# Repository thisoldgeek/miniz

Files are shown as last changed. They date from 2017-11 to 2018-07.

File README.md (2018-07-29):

# **miniz internet radio**
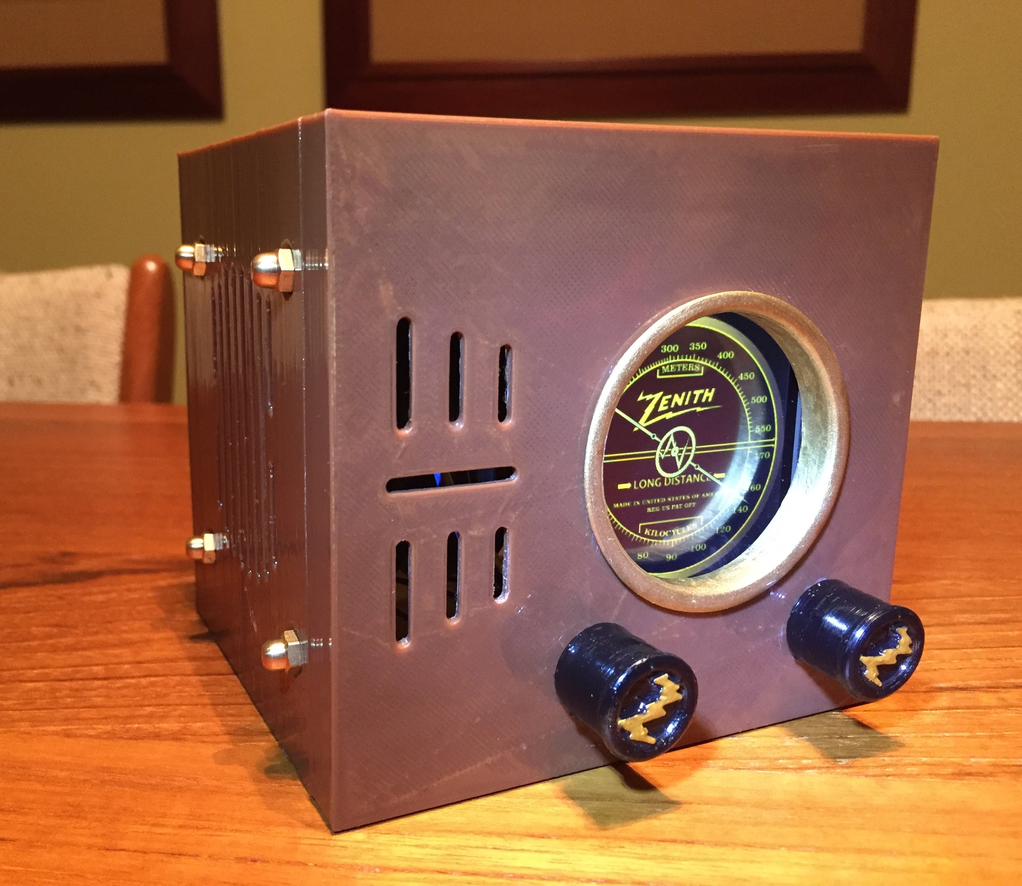
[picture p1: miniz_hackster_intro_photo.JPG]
miniz radio miniz Streaming Radio


# *Acknowledgements:*
My grateful appreciation is extended to the following, without whom this project would never exist, 
and to various Makers and members of the Open Source community for their continued sharing and support.

Tinkernut, https://www.hackster.io/tinkernut/diy-vintage-spotify-radio-using-a-raspberry-pi-bc3322

gerrelt, http://www.gerrelt.nl/RaspberryPi/wordpress/tutorial-stand-alone-squeezebox-server-and-player-for-bbq/

Oliver Derks, pi3d clock, https://groups.google.com/forum/#!topic/pi3d/qls3MQbtLiA

Bob Rathbone, rotary encoders, http://www.bobrathbone.com/raspberrypi/Raspberry%20Rotary%20Encoders.pdf

jinglemansweep on github, pyLMS, https://github.com/jinglemansweep/PyLMS

pi3d written by Tim Skillman, Paddy Gaunt, Tom Ritchford Copyright © 2012 - 2017, https://github.com/tipam/pi3d

Adafruit, various but especially, https://learn.adafruit.com/running-opengl-based-games-and-emulators-on-adafruit-pitft-displays/pitft-setup

trendblog: Mark Knoll, running headless pi, http://trendblog.net/raspberry-pi-basic-headless-setup-without-cables/

## *Description:*
A mono radio that plays favorite Pandora channels, internet radio stations, podcasts, playlists and 
local music using Logitech Media System and SqueezeLite. 

In the as-built version of this project, I'm using the free downloadable Deco typefont from Nick Curtis, called "Dubba Dubba". If you like Nick's work, please contribute a few $$ at: http://www.1001fonts.com/search.html?search=dubba+dubba&x=10&y=6

See the posting at (future):
http://thisoldgeek.blogspot.com

hackster.io miniz

## *Required Hardware:*
* raspberry pi zero W
* Adafruit piTFT Plus 3.5in display
* Small Speaker (3 inch full-range)
* Adafruit mono i2s amp, product 3006
* Adafruit perma-proto bonnet, product 3203
* Pimoroni On-Off/SHIM, Adafruit product 3581
* 2x rotary encoders with on/off switch, Adafruit product 377
* Optional but highly recommended: right-angle micro-usb to barrel connector
* Miscellaneous screws, nuts, standoffs, 22AWG wire

## *Fabrication:*
* 3D print files in STL_files folder
* 3D printed case required; other 3d parts optional
* See docs folder for 3D print settings

## *Configuration:*
* Install python programs and run scripts. See tutorial at hackster.io/thisoldgeek

Change IP Address to the IP of your miniz
Change player_id to your player from LMS/Settings/Information MAC Address

If you'd like to add additional "radio stations"

Consult the miniz/docs file name miniZ_dial_frequency_map.png and change the /miniz/miniz.py program

*format below is degrees:fav_number

favs = {82:0,57:1,30:2,8:3,352:4,333:5}

## *Testing:*
Use miniz/test_rotary_switches.py to test the tune and volume rotary encoder wiring and functions
Pin numbers in test_rotary_switches.py are the same as in miniz.py

## *REQUIRED:*
Intentionally blank

## *More Information:*
See the build log at https://www.hackster.io/thisoldgeek/miniz-tiny-streaming-radio-based-on-classic-zenith-cube-cbbc3e
## *Update 11-19-2017:*
Initial install.

## *UPDATE 2018-07-29: *
Added script miniz_dial_positions.py. Use this program to map a radio frequency on the dial to degrees of a circle
Degrees of a circle are used to play Favorites. 
*Usage*
Stop the zdial service.
Run the program, tune to a desired radio frequency on the dial. The degrees of circle for that frequency appears below
the center of the dial in white letters. Associate that degree with the favorite you wish to play at that frequency 
in the "favs:" dictionary of the miniz.py script

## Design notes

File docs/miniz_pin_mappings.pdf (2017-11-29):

MiniZ Streamer – Pin Mapping
All pin numbers refer to GPIO numbers •Amp Vin to Raspbery Pi 5V
•Amp GND to Raspbery Pi GND
•Amp DIN to Raspbery Pi #21
•Amp BCLK to Raspbery Pi #18
•Amp LRCLK to Raspbery Pi #19
•Volume/Rotary Encoder Up =#27 Clockwise/CW •Volume/Rotary Encoder Down = #23 CounterClockwise/CCW •Volume/On/Off Switch = #3 (SCL) Shutdown/On
•Display and Tune/Rotary Encoder Up = #13 Clockwise/CW
•Display and Tune/Rotary Encoder Down = #12 CounterClockwise/CCW •Display and Tune/Switch = #6 Screen Choice
•piTFT : uses hardware SPI (SCK, MOSI, MISO, CE0, CE1)
•piTFT: also uses GPIO #25 and #24. GPIO #18 can be used to PWM dim the backlight, but that is used by the Amp; to clear the display (turn it “black”) in pi3d use display.clear()
Currently unused: 5, 16, 20

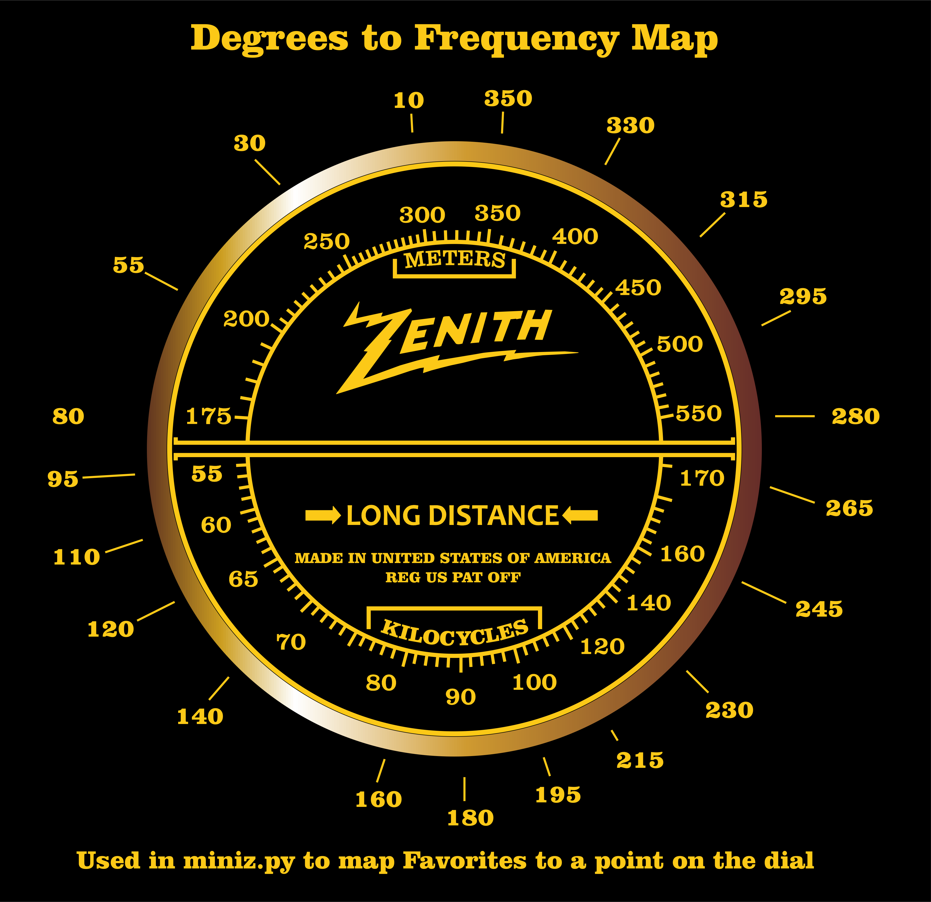
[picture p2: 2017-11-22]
docs/miniZ_dial_frequency_map.png

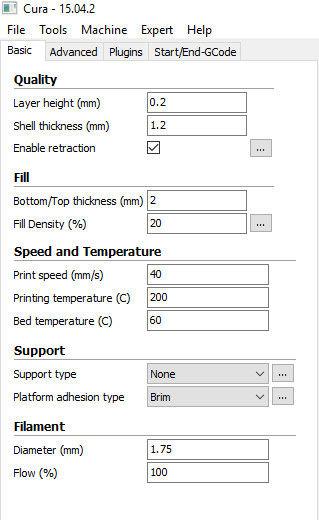
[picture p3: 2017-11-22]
docs/miniz_Cura_bezel_settings.png

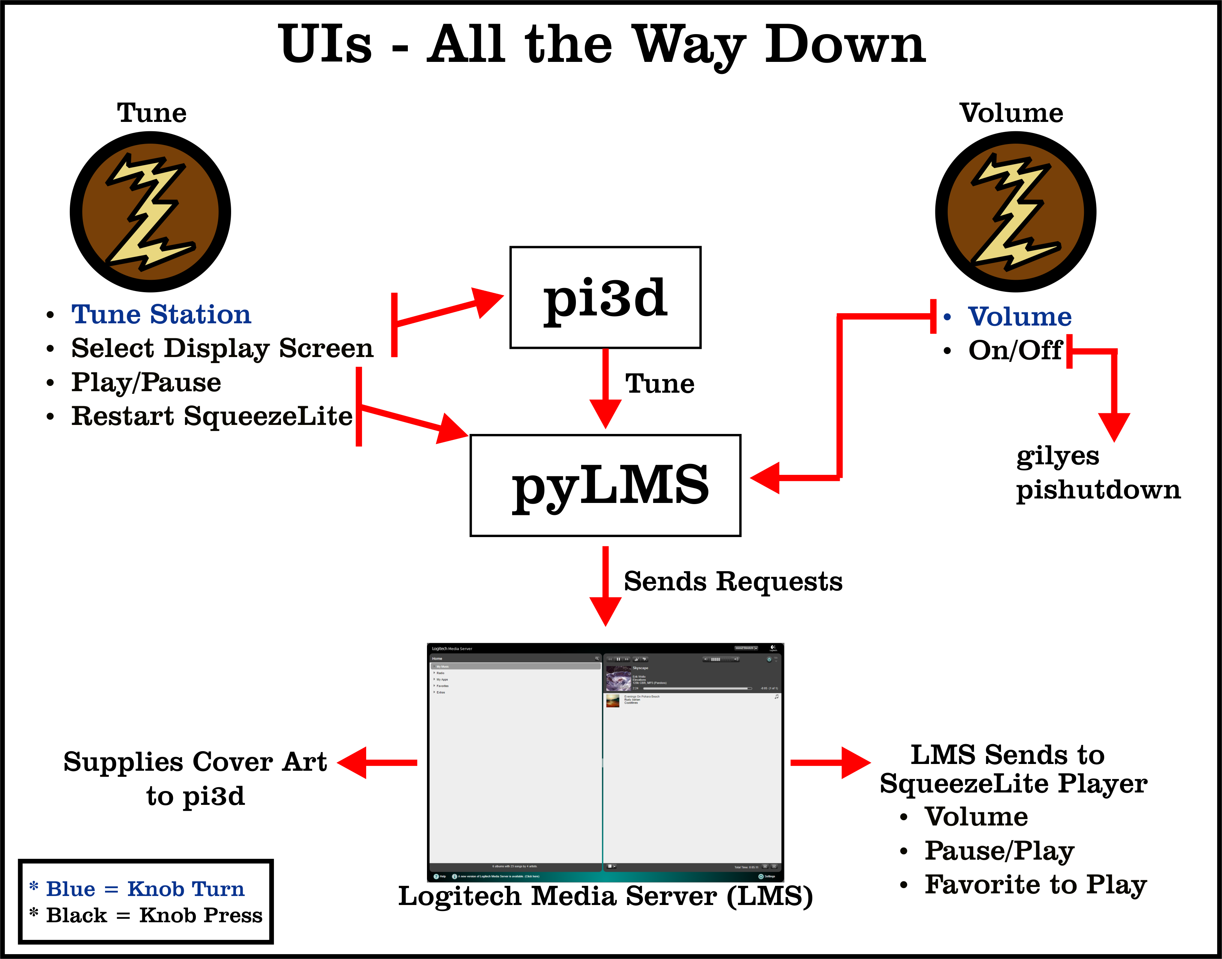
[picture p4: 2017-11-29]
docs/UI_Explained.png

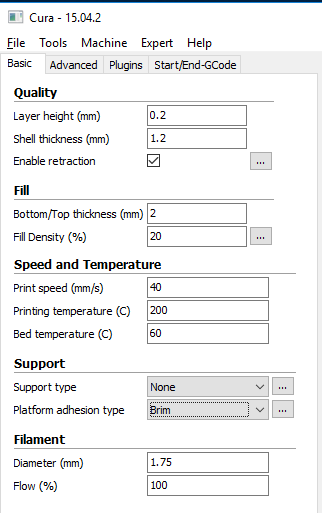
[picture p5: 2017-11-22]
docs/miniz_Cura_knob_settings.png

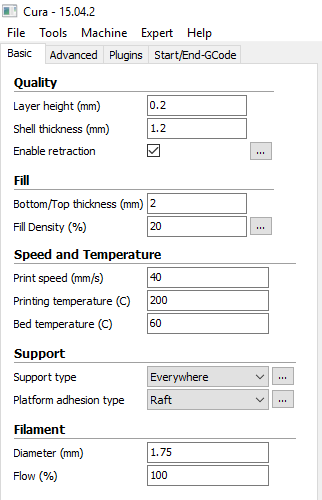
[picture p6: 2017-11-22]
docs/miniz_Cura_case_settings.png

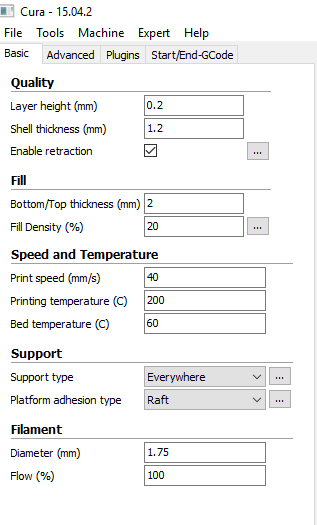
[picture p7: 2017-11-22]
docs/miniz_Cura_face_settings.png

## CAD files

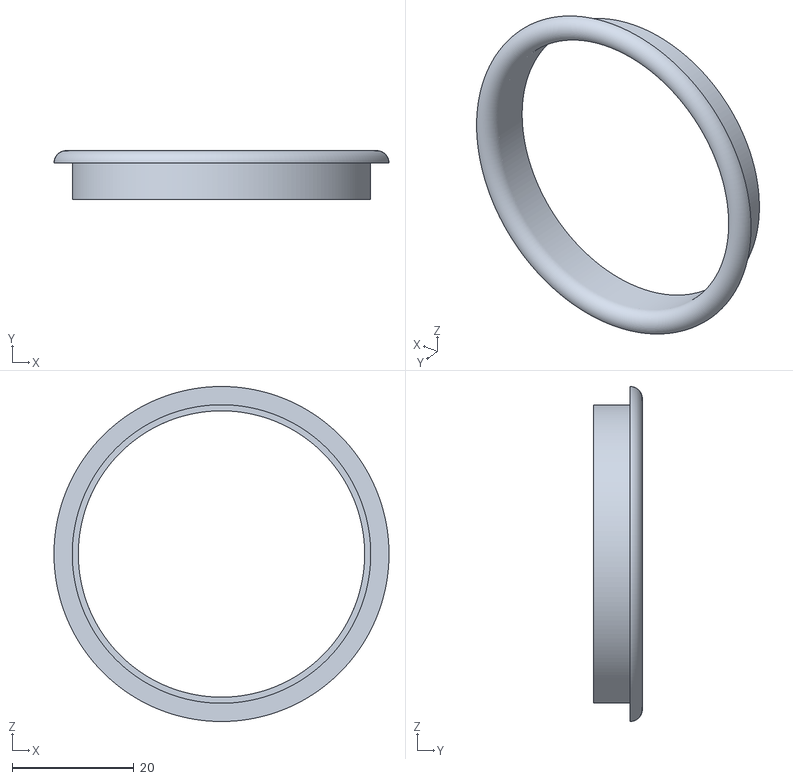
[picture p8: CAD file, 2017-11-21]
STL_files/miniz_bezel.stl
55.0 x 8.00 x 55.0

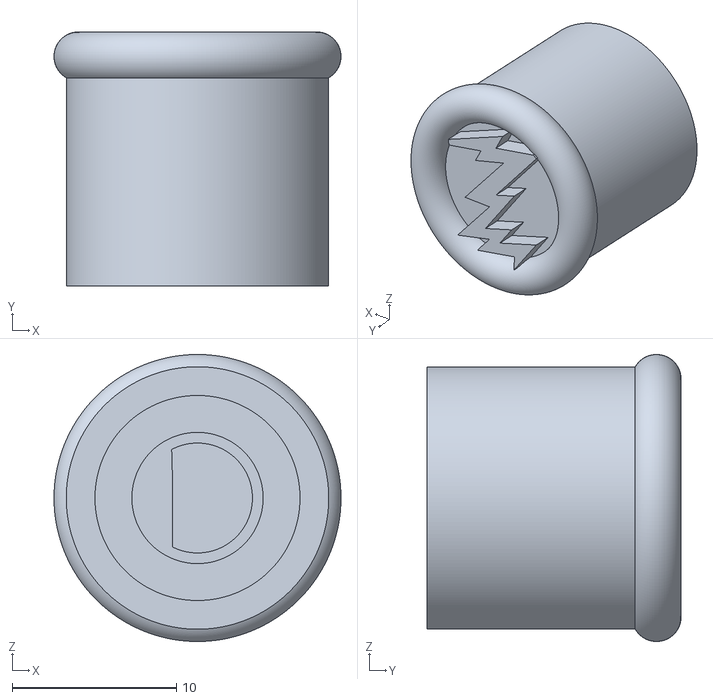
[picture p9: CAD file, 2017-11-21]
STL_files/miniz_knob.stl
17.5 x 15.5 x 17.5

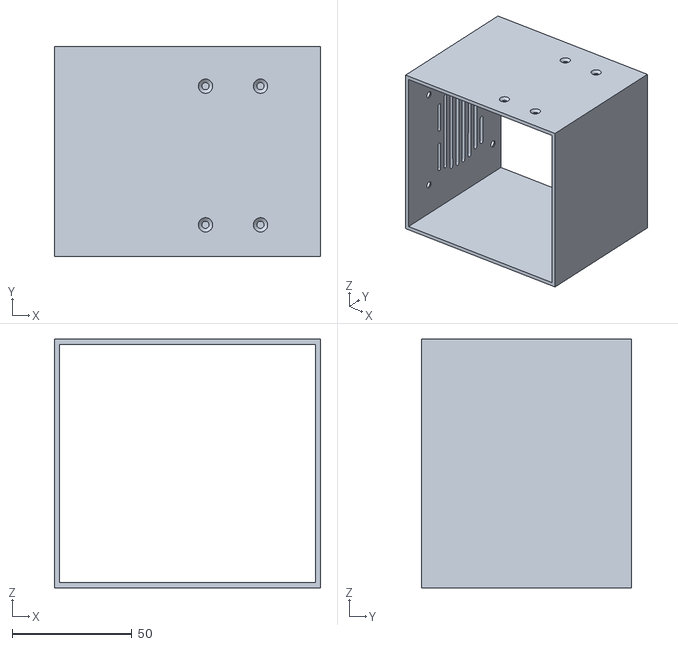
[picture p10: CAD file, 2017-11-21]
STL_files/miniz_case.stl
111.3 x 88.0 x 104.0

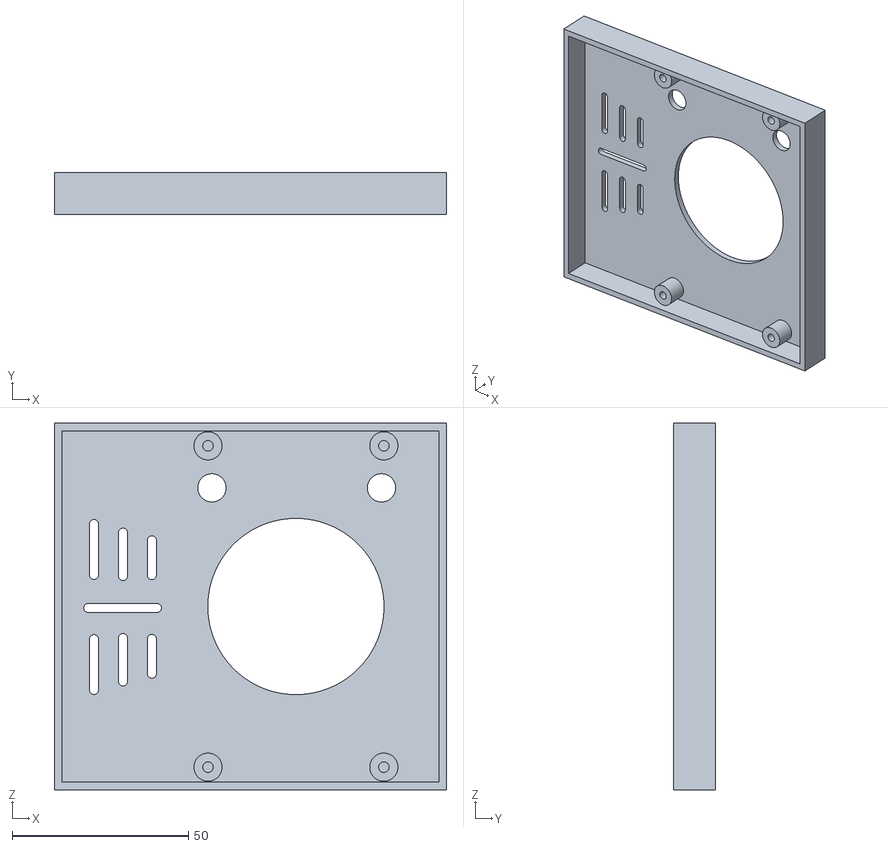
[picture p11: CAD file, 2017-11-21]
STL_files/miniz_face.stl
111.3 x 12.0 x 104.0

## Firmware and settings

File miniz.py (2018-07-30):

#!/usr/bin/python3

import pi3d
import time
import os
from PIL import Image, ImageDraw
from time import sleep
from rotary_class import RotaryEncoder
from pylms.server import Server
from pylms.player import Player
import textwrap

#sc = Server(hostname="192.168.0.211", port=9090, username="user", password="password")

# CHANGE the following to your LMS IP Address: hostIP, player_id
hostIP = '192.168.0.211'	# Change to the IP Address of your Logitech Media Server (LMS) - check your router

# insert miniz player MAC address here from LMS/Settings/Information
player_id = 'b8:27:eb:93:bb:81'

sc = Server(hostname=hostIP, port=9090)	# used for volume and play/pause
scNP = Server(hostname=hostIP, port=9090)	# used only to get Now Playing cover.jpg

sleep(60)     # allow time for LMS to start, otherwise get ConnectionError 111
sc.connect()
scNP.connect()

sq = sc.get_player(player_id)
sqNP = scNP.get_player(player_id)  # UGLY KLUDGE! Avoids conflict with volume routine which caused bad refresh on album cover.jpg

DISPLAY = pi3d.Display.create(use_pygame=True, samples=4)
DISPLAY.set_background(0,0,0,1) #r,g,b and alpha
shader = pi3d.Shader("uv_flat")
CAMERA = pi3d.Camera(is_3d=False)

# Radio Dial Sprites
radio_needle = pi3d.ImageSprite("/home/pi/miniz/textures/needle.png", shader,  w=64.0,  h=288.0,  x=0.0, y=-30.0, z=4.0)

# dial below was named miniZ_Full_simple_dial_v2_metal_ring.png in dev
radio_dial = pi3d.ImageSprite("/home/pi/miniz/textures/dial.png",  shader,  w=320.0,  h=320.0,  x=0.0, y=-30.0, z=6.0) 

# Clock Face Sprites
clock_face = pi3d.ImageSprite("/home/pi/miniz/textures/clock_face.png",  shader,  w=320.0,  h=320.0,  x=0.0, y=-30.0, z=6.0)
clock_hour = pi3d.ImageSprite("/home/pi/miniz/textures/clock_hour_hand.png", shader,  w=32.0,  h=176.0,  x=0.0, y=-30.0, z=4.0)
clock_min  = pi3d.ImageSprite("/home/pi/miniz/textures/clock_minute_hand.png", shader,  w=16.0,  h=156.0,  x=0.0, y=-30.0, z=4.0)

global myFont
# colors
gold=(233,215,127) # RGB Values
white=(1,1,1)
black=(0,0,0)
blue=(0,0,255)

myFont = pi3d.Font("/home/pi/miniz/fonts/DubbaDubbaNF.ttf", gold, font_size = 30)   #load ttf font and set the font color to gold


# Define GPIO inputs for Tuning/Menu Select
TUNE_A = 13	# Pin xx CW / Dial UP
TUNE_B = 12	# Pin xx CCW / Dial Down
TUNE_BUTTON = 6	# Pin x  Switch 

# Define GPIO inputs for Volume 
VOLUME_A = 27
VOLUME_B = 23
# VOLUME Button is used on Pimoroni On Off SHIM 
# Defined here to complete callback; not used in routine
VOLUME_BUTTON = 4

degrees =  57
prev_degrees = 0
station_cmd = 'favorites playlist play item_id:'
increment = 1
screen_num = 1
radio_needle_rot = degrees
start_time = time.time()
curr_album  = None
prev_album = curr_album

# format below is degrees:fav_number
favs = {82:0,57:1,30:2,8:3,352:4,333:5}
# in order, this maps degrees to:  175, 200, 250, 300, 350 and 400 meters
# on the visible radio dial

# This is the event callback routine to handle tune knob events
def tune_knob_event(event):
 handle_tune_event(event)

 return

# This is the event callback routine to handle volume knob events
def volume_knob_event(event):
 handle_volume_event(event) 

 return

# This is the event callback routine to handle dial tune events
def handle_tune_event(event):
	global degrees
	global increment
	global radio_needle_rot
	global prev_station
	global station_req
	global start_time    # Start timer for BUTTONDOWN Event
	global buttonTime    # Variable holds how long button was held down

	if event == RotaryEncoder.CLOCKWISE:
           #print("Clockwise")
           degrees = degrees - increment
	elif event == RotaryEncoder.ANTICLOCKWISE:
           #print("Anticlockwise")
           degrees = degrees + increment
	elif event == RotaryEncoder.BUTTONDOWN:
         #  print("Button down")
		start_time = time.time()
	elif event == RotaryEncoder.BUTTONUP:
		#print("Button up")
		buttonTime = time.time() - start_time # How long was the button down?
		handle_tune_button(buttonTime)

	valid_sta = favs.get(degrees)

	if valid_sta is not None:
            prev_degrees = degrees
            tune_fav = station_cmd + str(favs[degrees]) # format station play request
            sq.request(tune_fav)

	if event == RotaryEncoder.CLOCKWISE:
		if degrees <= 0:
		    degrees = 360

	if event == RotaryEncoder.ANTICLOCKWISE:
	 	if degrees > 360:
		    degrees = 0
	#print(degrees)
	radio_needle_rot = degrees
	sleep(.1)

	return

# Action to take based on how long tune button is pressed
def handle_tune_button(buttonVal):
	global screen_num	# Current screen to display

	if  .1 <= buttonVal < 2:	# Count to 2 and release button
		sq.toggle()	# toggle pause/play
	elif 2 <= buttonVal < 4:	# Count to 4 and release button
		DISPLAY.clear()
		if   screen_num  == 1:
			screen_num = 2	#show clock
		elif screen_num == 2:
			screen_num = 3	# Show cover art
		elif screen_num == 3:
			screen_num = 1  # Back to beginning, show the radio dial
	elif 4 <= buttonVal < 8:	# Count to 8 and release button
		print ("REALLY Long Push!")
		os.system("systemctl restart squeezelite")	# Do this if sound is distorted; player will resume play on restart

	return

# This is the event callback routine to handle volume events
def handle_volume_event(event):

	if event == RotaryEncoder.CLOCKWISE:
 		sq.volume_up()
	elif event == RotaryEncoder.ANTICLOCKWISE:
 		sq.volume_down()
	# The button on volume is connected to GPIO 4 via Pimoroni On Off SHIM
	sleep(.25)

	return

# Define the switches
tune_knob = RotaryEncoder(TUNE_A,TUNE_B,TUNE_BUTTON, tune_knob_event)
volume_knob = RotaryEncoder(VOLUME_A, VOLUME_B, VOLUME_BUTTON, volume_knob_event)
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

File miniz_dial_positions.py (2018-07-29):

#!/usr/bin/python3

# use this program to map the radio dial to the degrees of a circle
# favorites are played when the radio needle passes over the associated degree
# this mapping occurs in dictionary named 'favs' below

import pi3d
import time
from time import sleep
from rotary_class import RotaryEncoder
# Works as of 03-03-2017 03:57PM
# Added refinements to dial: numbers, inner dial, bezel for magic eye
# 03-09-2017 05:58PM
# rot2 = -60 equals "2 o'clock" on the dial
# rot2 = 0 equals "12 o'clock" on the dial
# rot2 = 30  equals "11 o'clock" on the dial
# Thus you could have 12 radio stations/presets at 30 degree intervals around the dial

#DISPLAY = pi3d.Display.create(w=999, h=999, samples=4)
# use_pygame=True, with no w,h,x,y values yields drawing surface full screen no borders

DISPLAY = pi3d.Display.create(use_pygame=True, samples=4)
DISPLAY.set_background(0,0,0,1) #r,g,b and alpha
shader = pi3d.Shader("uv_flat")
CAMERA = pi3d.Camera(is_3d=False)

# colors
gold=(233,215,127) # RGB Values
white=(255,255,255)
black=(0,0,0)
blue=(0,0,255)

myFont = pi3d.Font("/home/pi/miniz/fonts/DubbaDubbaNF.ttf", white, font_size = 30)   #load ttf font and set the font color to blue

# Radio Dial Sprites
needle = pi3d.ImageSprite("/home/pi/miniz/textures/needle.png", shader,  w=64.0,  h=288.0,  x=0.0, y=-30.0, z=4.0)

# dial below was named miniZ_Full_simple_dial_v2_metal_ring.png in dev
backgr = pi3d.ImageSprite("/home/pi/miniz/textures/dial.png",  shader,  w=320.0,  h=320.0,  x=0.0, y=-30.0, z=6.0) 


# Define GPIO inputs for Tuning/Menu Select
PIN_A = 13	# Pin xx CW / Dial UP
PIN_B = 12	# Pin xx CCW / Dial Down
BUTTON = 6	# Pin x  Switch 

degrees =  80
prev_station = 0
station_cmd = 'favorites playlist play item_id:'
increment = 1
eye_rot = 0
needle_rot =  degrees
favs = {0:0,30:1,60:2,90:3,120:4,150:5}

# This is the event callback routine to handle events
def switch_event(event):
	global degrees
	global increment
	global needle_rot
	global prev_station
	global station_req

	if event == RotaryEncoder.CLOCKWISE:
           print("Clockwise")
           degrees = degrees - increment
	elif event == RotaryEncoder.ANTICLOCKWISE:
           print("Anticlockwise")
           degrees = degrees + increment
	#elif event == RotaryEncoder.BUTTONDOWN:
         #  print("Button down")
	#elif event == RotaryEncoder.BUTTONUP:
        #   print("Button up")
	#if degrees % 30 == 0:   # if a 30 degree increment
        #    prev_station = degrees
        #   tune_fav = station_cmd + str(favs[degrees]) # format station play request
        #    sq.request(tune_fav)
	if event == RotaryEncoder.CLOCKWISE:
		if degrees <= 0:
		    degrees = 360

	if event == RotaryEncoder.ANTICLOCKWISE:
	 	if degrees > 360:
		    degrees = 0
	print(degrees)
	needle_rot = degrees
	sleep(.2)
	return

# Define the switch
rswitch = RotaryEncoder(PIN_A,PIN_B,BUTTON,switch_event)


while DISPLAY.loop_running():
  needle.rotateToZ(needle_rot)
  needle.draw()
  backgr.draw()
  frequency = pi3d.String(camera=CAMERA, is_3d=False, font=myFont, string=str(needle_rot),  x=0, y=-90.0, z=1.0)
  frequency.set_shader(shader)
  frequency.draw()
  sleep(.05)

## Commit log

2017-11-21 added stl files
    [miniz_bezel.stl, miniz_case.stl, miniz_face.stl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]
2017-11-22 add Cura print settings
2017-11-22 add Cura print settings to README
2017-11-22 add STL Folder Location to README
2017-11-29 add pin map to docs
2017-12-01 add bonnet wiring diagram
2017-12-02 correct wiring diagram
2017-12-02 corrected wiring diagram
2017-12-05 fixed bug in cover art address
    [miniz.py]
2017-12-09 add .distutils.cfg
    [.distutils.cfg]
2017-12-10 fix comment in test_rotary_switches.py
    [test_rotary_switches.py]
2017-12-12 fix bug with track display same album
    [miniz.py]
